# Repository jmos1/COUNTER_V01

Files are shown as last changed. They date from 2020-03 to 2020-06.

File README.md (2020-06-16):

# COUNTER_V01
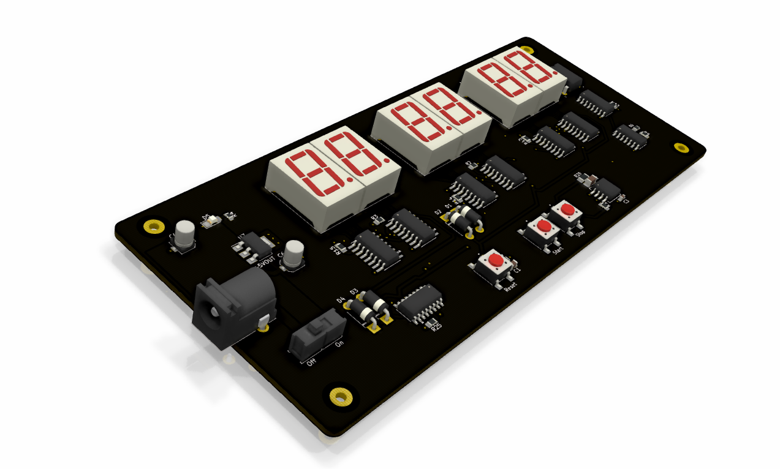
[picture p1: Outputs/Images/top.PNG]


### Summary: ###
  This board is a seven-segment display stopwatch that can count up to 99 minutes.
  It uses the popular 4XXX series logic chips to drive the displays, as well as a few other popular components
  like the 555 timer to implement other functions.

  The BOM, schematic PDF, and gerber files are all accessible in the _'Outputs/'_ folder. 
  Other project files are not included because they add clutter and can be generated from the project itself in KiCad.
  Thanks.
  
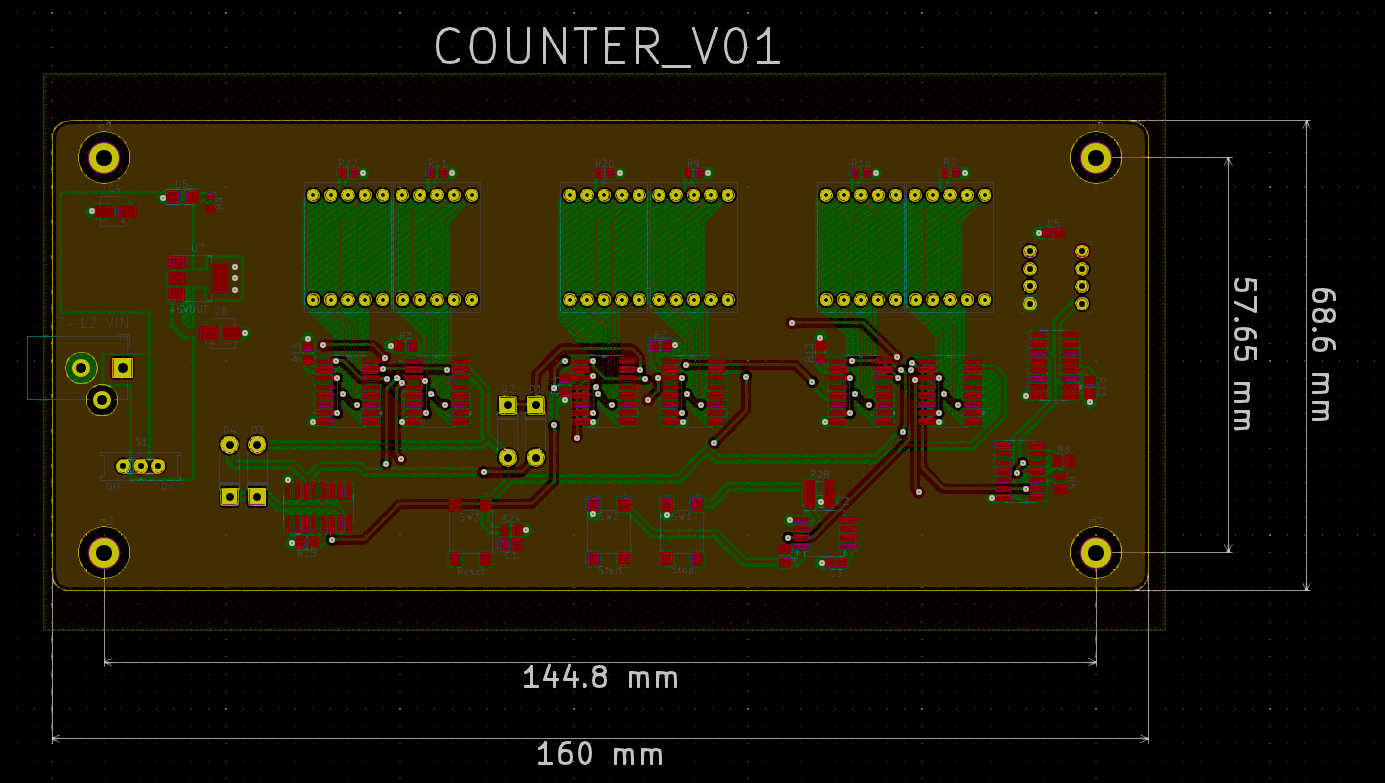
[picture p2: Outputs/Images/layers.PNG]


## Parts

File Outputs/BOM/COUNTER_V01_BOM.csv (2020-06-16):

Comment | MPN | Manufacturer | Part Number | Supplier | Quantity
CD4026BNSR | CD4026BNSR | Texas Instruments | 296-28693-6-ND | Digikey | 6
CD4060BM96 | CD4060BM96 | Texas Instruments | 296-31513-1-ND | Digikey | 1
CD4017BM96 | CD4017BM96 | Texas Instruments | 296-25940-1-ND | Digikey | 1
8 POS DIP SOCKET | 08-3518-10 | Aries Electronics | A400-ND | Digikey | 1
SN74LS74ADR | SN74LS74ADR | Texas Instruments | 296-14899-1-ND | Digikey | 1
NE555PSR | NE555PSR | Texas Instruments | 296-6502-1-ND | Digikey | 1
LM7805MPX/NOPB | LM7805MPX/NOPB | Texas Instruments | 296-44518-1-ND | Digikey | 1
120R | ERJ-PA3J121V | Panasonic | P120BZCT-ND | Digikey | 6
1KR | ERJ-PB6D1001V | Panasonic | P21019CT-ND | Digikey | 11
220R | ERJ-PA3F2200V | Panasonic | P220BYCT-ND | Digikey | 1
10KR | ERA-8AEB103V | Panasonic | P10KBCCT-ND | Digikey | 1
10uF,16V | EEE-1CA100SR | Panasonic | PCE3878CT-ND | Digikey | 2
10nF,25V | C0603C103K3RACTU | KEMET | 399-7840-1-ND | Digikey | 1
1uF,25V | C0805C105K3RACTU | KEMET | 399-8004-1-ND | Digikey | 1
10uF,25V | C1206C106M3PACTU | KEMET | 399-8153-1-ND | Digikey | 1
B3FS-1010P | B3FS-1010P | Omron Electronics | SW1440CT-ND | Digikey | 3
GRN | QTLP650D4TR | Everlight Electronics Co Ltd | 1080-1419-2-ND | Digikey | 1
EG1218 | EG1218 | E-Switch | EG1903-ND | Digikey | 1
PJ-102AH | PJ-102AH | CUI Devices | CP-102AH-ND | Digikey | 1
SC56-21GWA | SC56-21GWA | Kingbright | 754-1704-5-ND | Digikey | 6

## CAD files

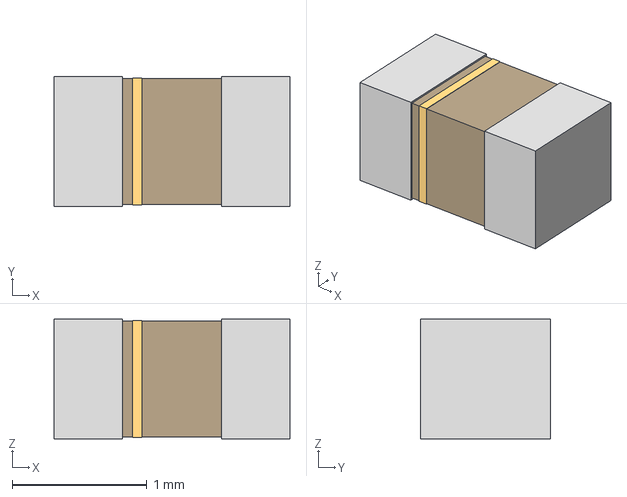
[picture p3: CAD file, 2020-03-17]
3D Models/STEP/fuse_0603-M.step
1.75 x 0.966 x 0.889 mm

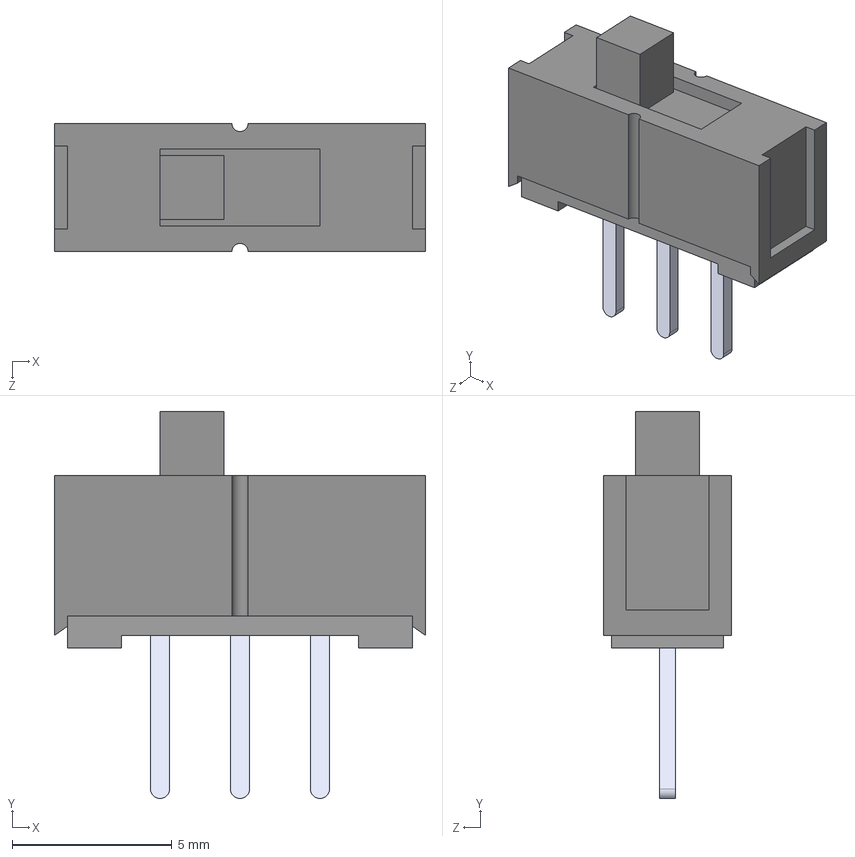
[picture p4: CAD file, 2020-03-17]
3D Models/STEP/SPDT_EG1218.STEP
11.6 x 12.1 x 4.00 mm

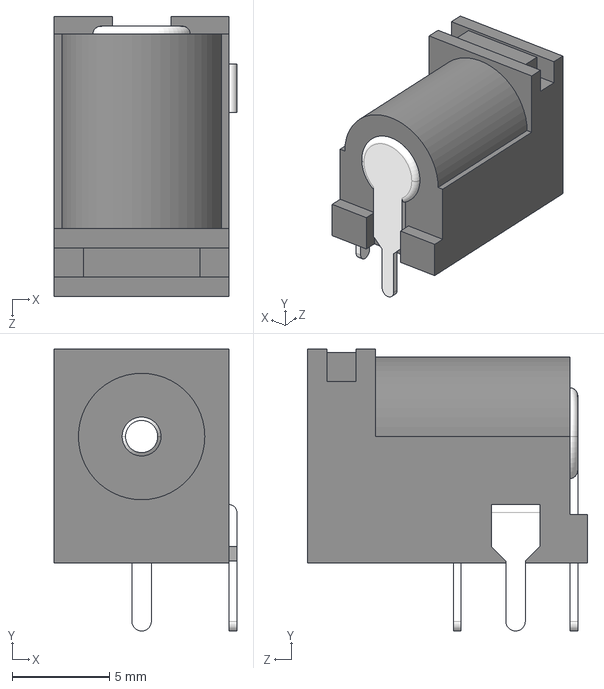
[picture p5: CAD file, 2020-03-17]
3D Models/STEP/BarrelJack_PJ-102AH.STEP
9.40 x 14.5 x 14.4 mm

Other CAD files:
3D Models/STEP/fuse_0603-L.step
3D Models/STEP/fuse_0603.step

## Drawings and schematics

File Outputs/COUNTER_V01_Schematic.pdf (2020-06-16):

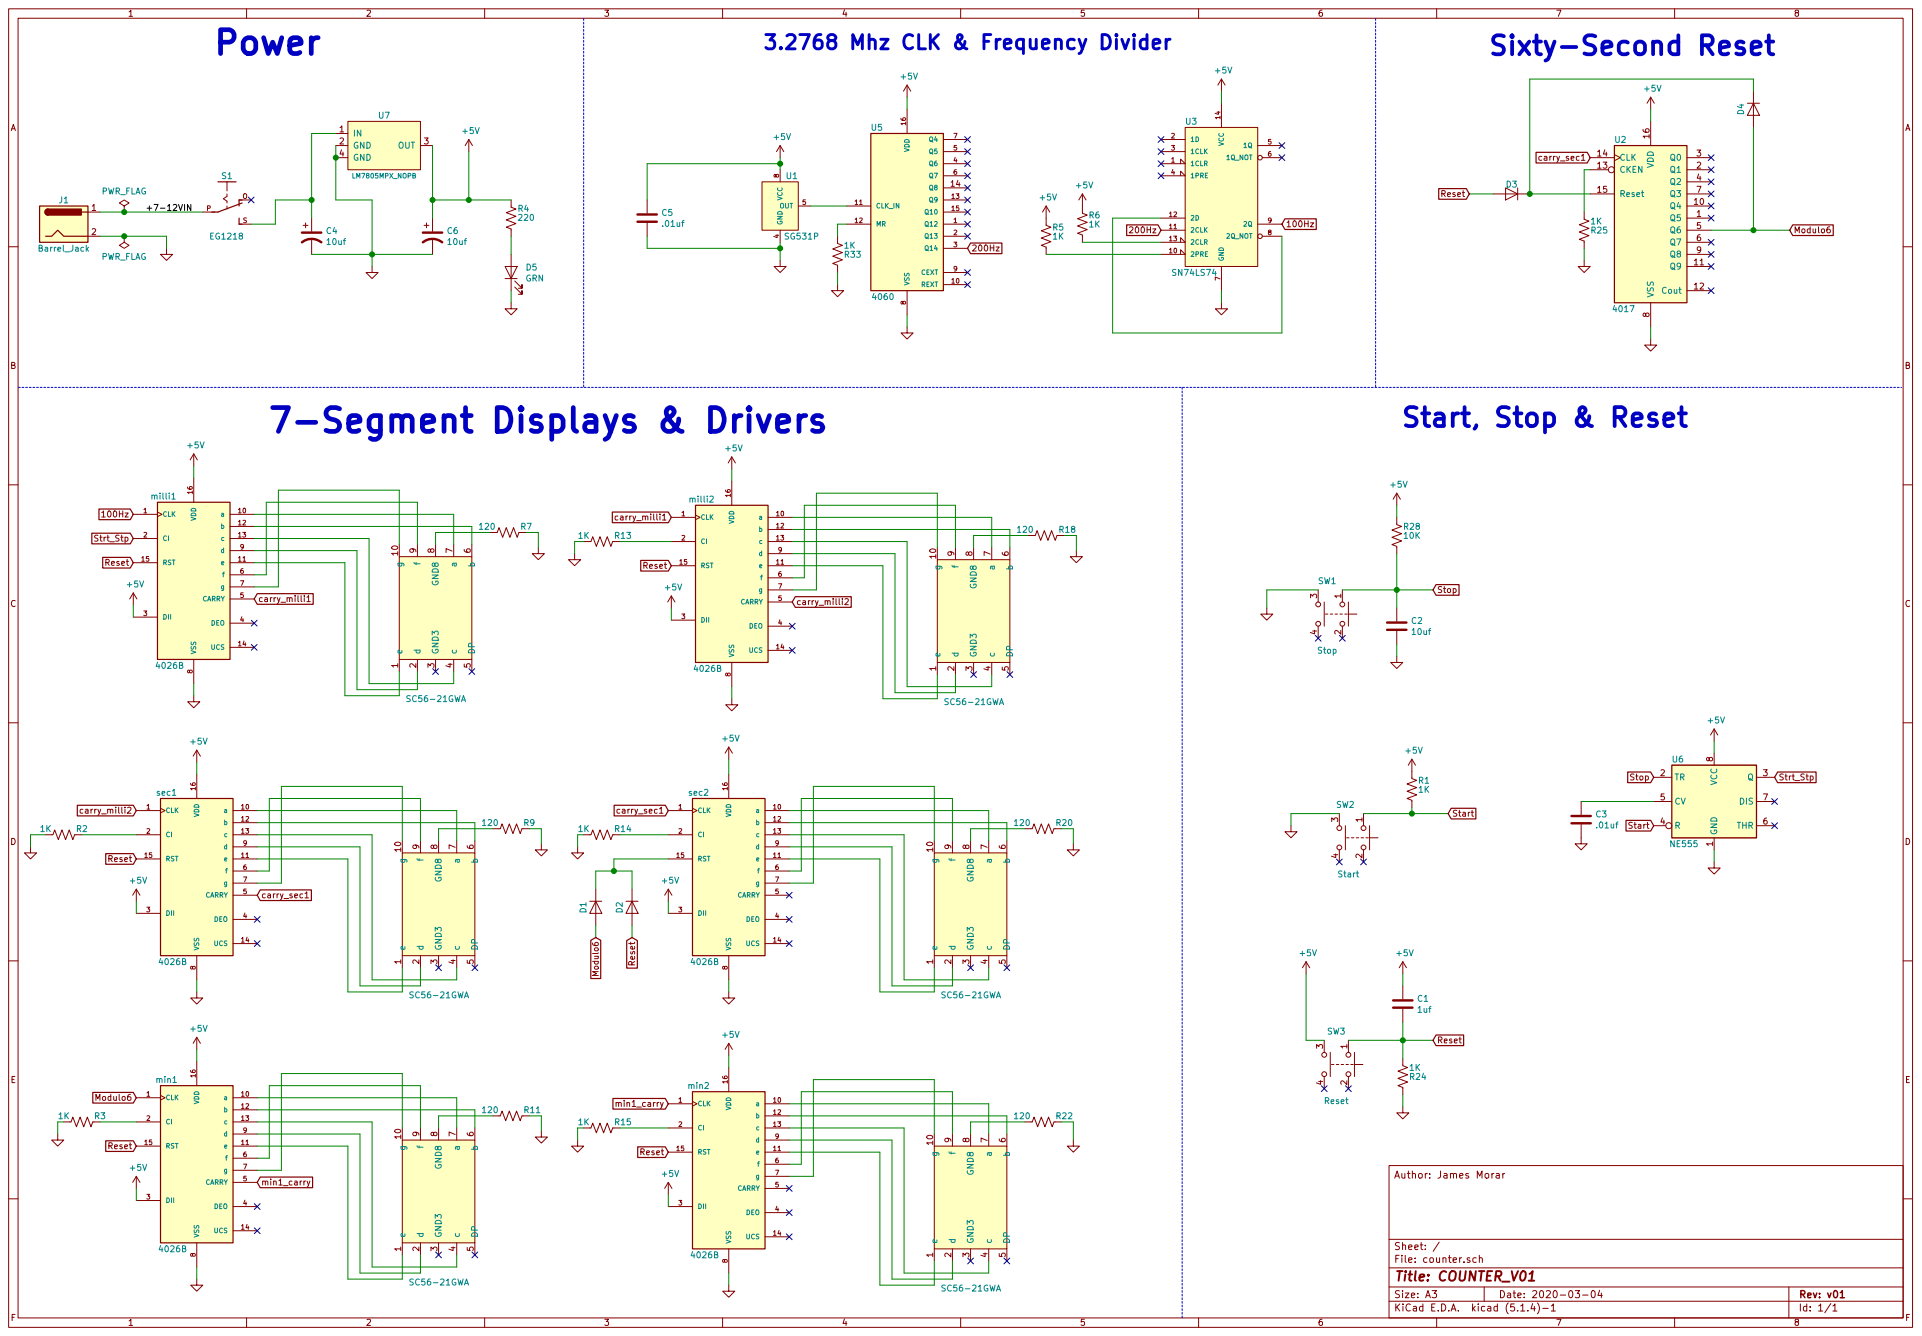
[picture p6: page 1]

File: counter.sch Sheet: / Author: James Morar

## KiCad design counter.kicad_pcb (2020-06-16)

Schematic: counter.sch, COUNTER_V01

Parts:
7seg_milli1, 7seg_milli2, 7seg_min1, 7seg_min2, 7seg_sec1, 7seg_sec2: SC56-21GWA
C1: 1uf; CAPC2012X140N
C2: 10uf; CAPC3216X110N
C3, C5: .01uf; CAPC1608X90
C4, C6: 10uf; CAPAE430X550N
D1, D2, D3, D4: D; D_DO-41_SOD81_P7.62mm_Horizontal
D5: GRN; LED_1206_3216Metric_Castellated
J1: Barrel_Jack; BarrelJack_CUI_PJ-102AH_Horizontal
R1, R2, R3, R5, R6, R13, R14, R15, R24, R25, R33: 1K; RESC2012X70N
R4: 220; RESC1608X55N
R7, R9, R11, R18, R20, R22: 120; RESC1608X55N
R28: 10K; RESC3216X70N
S1: EG1218
SW1: Stop; SW_B3FS-1010P
SW2: Start; SW_B3FS-1010P
SW3: Reset; SW_B3FS-1010P
U1: SG531P; SOCKET_DIP-8_7.62mm_Conn
U2: 4017; CD4017BM96
U3: SN74LS74; SN74LS74ADR
U5: 4060; CD4060BM96
U6: NE555; NE555PSR
U7: LM7805MPX_NOPB; SOT-223
milli1, milli2: 4026B; CD4026BNSR
min1, min2: 4026B; CD4026BNSR
sec1, sec2: 4026B; CD4026BNSR

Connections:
100Hz: U3.9, milli1.1
200Hz: U3.11, U5.3
+5V: C1.1, C5.1, C6.1, R1.1, R4.2, R5.1, R6.1, R28.1, SW3.3, U1.8, U2.16 (VDD), U3.14, U5.16, U6.8 (VCC), U7.3, milli1.3, milli1.16, milli2.3, milli2.16, min1.3, min1.16, min2.3, min2.16, sec1.3, sec1.16, sec2.3, sec2.16
/+7-12VIN: J1.1, S1.P
GND: C2.2, C3.2, C4.2, C5.2, C6.2, D5.1 (K), J1.2, R2.2, R3.2, R7.1, R9.1, R11.1, R13.2, R14.2, R15.2, R18.1, R20.1, R22.1, R24.2, R25.2, R33.2, SW1.3, SW2.3, U1.4, U2.8 (VSS), U3.7, U5.8, U6.1 (GND), U7.2, U7.4, milli1.8, milli2.8, min1.8, min2.8, sec1.8, sec2.8
Modulo6: D1.2 (A), D4.2 (A), U2.5 (Q6), min1.1
unnamed: 7seg_milli1.1, milli1.11
unnamed: 7seg_milli1.2, milli1.9
unnamed: 7seg_milli1.4, milli1.13
unnamed: 7seg_milli1.6, milli1.12
unnamed: 7seg_milli1.7, milli1.10
unnamed: 7seg_milli1.8, R7.2
unnamed: 7seg_milli1.9, milli1.6
unnamed: 7seg_milli1.10, milli1.7
unnamed: 7seg_milli2.1, milli2.11
unnamed: 7seg_milli2.2, milli2.9
unnamed: 7seg_milli2.4, milli2.13
unnamed: 7seg_milli2.6, milli2.12
unnamed: 7seg_milli2.7, milli2.10
unnamed: 7seg_milli2.8, R18.2
unnamed: 7seg_milli2.9, milli2.6
unnamed: 7seg_milli2.10, milli2.7
unnamed: 7seg_min1.1, min1.11
unnamed: 7seg_min1.2, min1.9
unnamed: 7seg_min1.4, min1.13
unnamed: 7seg_min1.6, min1.12
unnamed: 7seg_min1.7, min1.10
unnamed: 7seg_min1.8, R11.2
unnamed: 7seg_min1.9, min1.6
unnamed: 7seg_min1.10, min1.7
unnamed: 7seg_min2.1, min2.11
unnamed: 7seg_min2.2, min2.9
unnamed: 7seg_min2.4, min2.13
unnamed: 7seg_min2.6, min2.12
unnamed: 7seg_min2.7, min2.10
unnamed: 7seg_min2.8, R22.2
unnamed: 7seg_min2.9, min2.6
unnamed: 7seg_min2.10, min2.7
unnamed: 7seg_sec1.1, sec1.11
unnamed: 7seg_sec1.2, sec1.9
unnamed: 7seg_sec1.4, sec1.13
unnamed: 7seg_sec1.6, sec1.12
unnamed: 7seg_sec1.7, sec1.10
unnamed: 7seg_sec1.8, R9.2
unnamed: 7seg_sec1.9, sec1.6
unnamed: 7seg_sec1.10, sec1.7
unnamed: 7seg_sec2.1, sec2.11
unnamed: 7seg_sec2.2, sec2.9
unnamed: 7seg_sec2.4, sec2.13
unnamed: 7seg_sec2.6, sec2.12
unnamed: 7seg_sec2.7, sec2.10
unnamed: 7seg_sec2.8, R20.2
unnamed: 7seg_sec2.9, sec2.6
unnamed: 7seg_sec2.10, sec2.7
unnamed: C3.1, U6.5 (CV)
unnamed: C4.1, S1.S, U7.1
unnamed: D1.1 (K), D2.1 (K), sec2.15
unnamed: D3.1 (K), D4.1 (K), U2.15 (Reset)
unnamed: D5.2 (A), R4.1
unnamed: R2.1, sec1.2
unnamed: R3.1, min1.2
unnamed: R5.2, U3.10
unnamed: R6.2, U3.13
unnamed: R13.1, milli2.2
unnamed: R14.1, sec2.2
unnamed: R15.1, min2.2
unnamed: R25.1, U2.13 (CKEN)
unnamed: R33.1, U5.12
unnamed: U1.5, U5.11
unnamed: U3.8, U3.12
Reset: C1.2, D2.2 (A), D3.2 (A), R24.1, SW3.1, milli1.15, milli2.15, min1.15, min2.15, sec1.15
Start: R1.2, SW2.1, U6.4 (R)
Stop: C2.1, R28.2, SW1.1, U6.2 (TR)
Strt_Stp: U6.3 (Q), milli1.2
carry_milli1: milli1.5, milli2.1
carry_milli2: milli2.5, sec1.1
carry_sec1: U2.14 (CLK), sec1.5, sec2.1
min1_carry: min1.5, min2.1

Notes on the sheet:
Start, Stop & Reset
Power
3.2768 Mhz CLK & Frequency Divider
Sixty-Second Reset
7-Segment Displays & Drivers

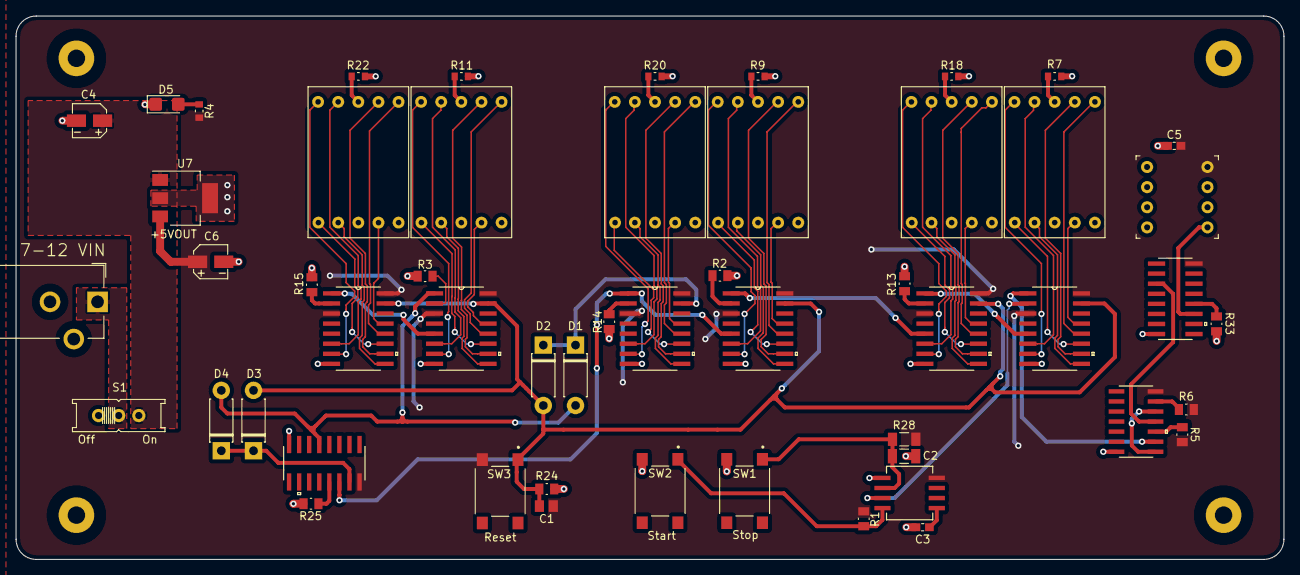
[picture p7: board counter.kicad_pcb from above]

Board: 2 copper layers, 160.0 x 68.6 mm, 57 parts (0 on the bottom side), 78 nets.

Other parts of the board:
m2, m2#2, m2#3, m2#4: MountingHole_2.2mm_M2_ISO7380_Pad

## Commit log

2020-03-07 First commit just to save. Board is still incomplete.
    [counter.kicad_pcb, counter.sch]
2020-03-07 Cleaned up schematic and pcb. Created annotations.
    [counter.kicad_pcb, counter.sch]
2020-03-09 Changed layout, organized traces, removed resistors from 7-seg displays
    [counter.kicad_pcb, counter.sch]
2020-03-17 added gerbers, footprints, schematic pdf, symbols, 3d models
    [BarrelJack_PJ-102AH.STEP, SPDT_EG1218.STEP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]
2020-03-26 Reorganized project and added missing carry_sec1 trace
    [Components.xlsx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]
2020-04-09 Rev 2 board. Added missing trace, gerbers, and schematic
    [counter-B_Cu.gbr, counter-B_Mask.gbr, counter-B_SilkS.gbr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]
2020-04-09 Schematic PDF addded
2020-06-16 Modifications to Schematic
    [BarrelJack_PJ-102AH.STEP, Components.xlsx, SPDT_EG1218.STEP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]
2020-06-16 Adding BOM
    [COUNTER_V01_BOM.csv]

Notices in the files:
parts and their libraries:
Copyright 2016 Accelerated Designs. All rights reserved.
